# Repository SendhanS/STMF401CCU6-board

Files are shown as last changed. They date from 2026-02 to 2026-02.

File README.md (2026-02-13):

# STMF401CCU6-board
STM32F4 series breakout board

The breakout board is based on the STM32F401CCU6 microcontroller in a QFN-48 package, chosen
for its high-performance ARM Cortex-M4 core and compact footprint, providing sufficient digital and
communication interfaces for typical embedded applications while fitting within the 50 × 50 mm
board area. Power regulation is handled by the TLV75801PDRV low-dropout linear regulator, selected
for its compact SOT-23-5 package and ability to convert a 5 V input from USB or header to a stable
3.3 V supply required by the STM32F401 and peripherals.
Peripheral pin mapping follows assignment specifications: five GPIO outputs, I2C1 on PB6/PB7, SPI1
on PA5/PA6/PA7, USART2 on PA2/PA3, and SWD interface on a 2×5 header including SWDIO, SWCLK,
SWO, NRST, 3.3 V, and GND. To minimize routing complexity, peripherals are mapped to ensure all
related pins are on the same side of the MCU, preventing excessive trace crossings and overlap. The
reset button is connected to NRST with a parallel 0.1 μF capacitor, and a user LED is connected to
PC13 via a 1.5 kΩ series resistor.
Power and layout considerations prioritize clean routing and manufacturability. The 3.3 V rail is
decoupled with four 100 nF capacitors near the MCU and a 10 μF bulk capacitor at the
TLV75801PDRV output. The 8 MHz crystal is placed close to the MCU with a restricted area around its
traces to prevent noise coupling. A solid GND pour covers both layers, connecting decoupling caps,
mounting holes, and headers. Trace widths are 0.4 mm for power and 0.15–0.2 mm for signals,
following standard PCB design practice.

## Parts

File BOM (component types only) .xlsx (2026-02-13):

Designator | Package | Value
J4 | 1×6 pin header | SPI
C1 | 0805 SMD | 10uf
C10, C2, C3, C6, C8 | 0603 SMD | 100nf
C11, C12 | 0603 SMD | 10uF
C4, C7 | 0402 SMD | 12p
C5 | 0603 SMD | 0.1uf
C9 | 0603 SMD | 4.7uf
D1 | 0603 SMD LED | BLUE
D2 | 0603 SMD LED | LED
J7 | 1×2 pin header | Conn_01x02_Pin
J4 | 1×4 pin header | I2C
H1, H2, H3, H4 | 4.3 mm mounting hole for M4 | MountingHole_Pad
J2 | USB-C 6P SMT | USB_C_Receptacle_PowerOnly_6P
J3 | 1×4 pin header | USART2
J6 | 1×5 pin header | Digital Output
R1, R3 | 0402 SMD resistor | 4.7k
R10, R2 | 0603 SMD resistor | 10k
R4 | 0603 SMD resistor | 1.5k
R5, R6, R9 | 0603 SMD resistor | 5.1k
R7 | 0603 SMD resistor | 1M
R8 | 0603 SMD resistor | 200k
RESET1 | SPST switch -SMT | ~
J1 | 2×5 pin header | SWD
U1 | QFN-48, 7×7 mm | STM32F401CCUx
U2 | WSON-6, 2×2 mm | TLV75801PDRV
Y1 | SMD 3225 4-pin crystal, 3.2×2.5 mm | 8MHz

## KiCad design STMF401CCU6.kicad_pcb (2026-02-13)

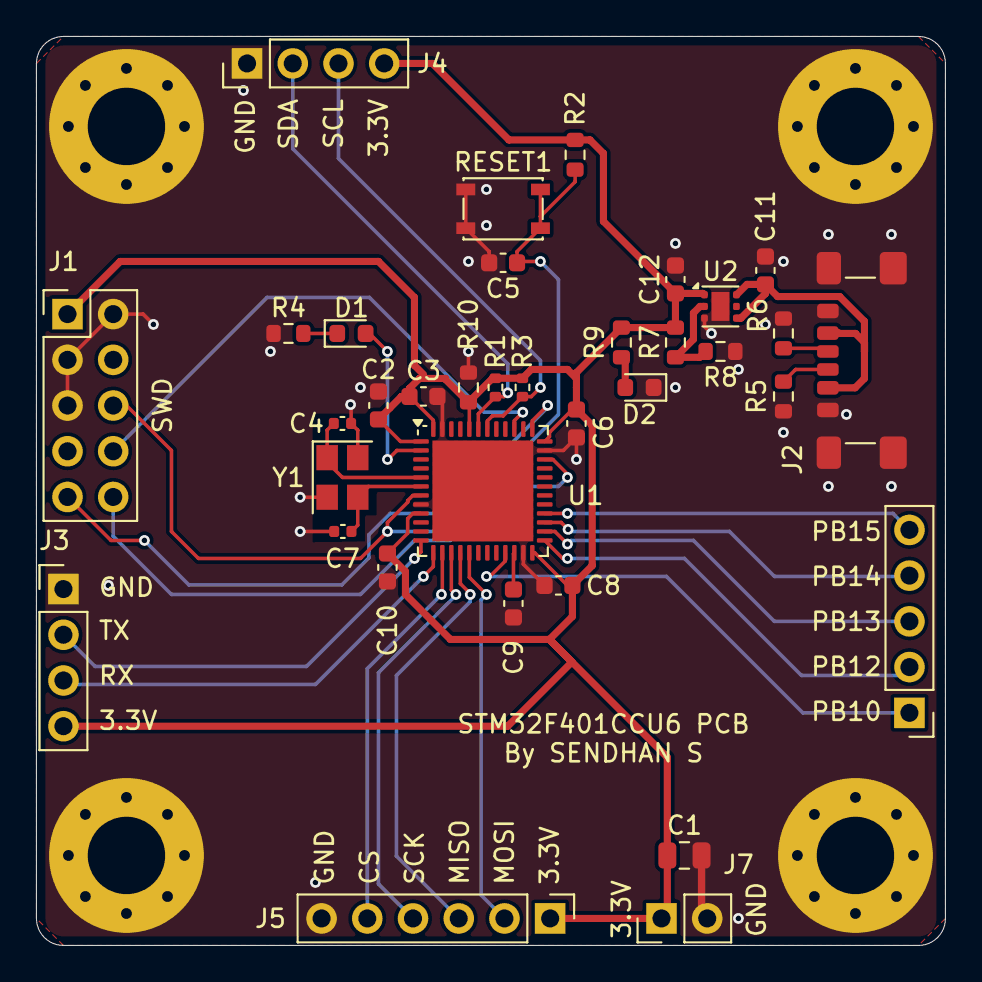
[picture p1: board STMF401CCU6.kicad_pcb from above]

Board: 2 copper layers, 50.5 x 50.5 mm, 39 parts (0 on the bottom side), 29 nets.

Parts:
3.3V: SPI; PinHeader_1x06_P2.54mm_Vertical
C1: 10uf; C_0805_2012Metric
C2, C3, C6, C8, C10: 100nf; C_0603_1608Metric
C4, C7: 12p; C_0402_1005Metric
C5: 0.1uf; C_0603_1608Metric
C9: 4.7uf; C_0603_1608Metric
C11, C12: 10uF; C_0603_1608Metric
D1: BLUE; LED_0603_1608Metric
D2: LED; LED_0603_1608Metric
GND: Conn_01x02_Pin; PinHeader_1x02_P2.54mm_Vertical
GND#2: I2C; PinHeader_1x04_P2.54mm_Vertical
H1, H2, H3, H4: MountingHole_Pad; MountingHole_4.3mm_M4_Pad_Via
J2: USB_C_Receptacle_PowerOnly_6P; USB_C_Receptacle_GCT_USB4135-GF-A_6P_TopMnt_Horizontal
J3: USART2; PinHeader_1x04_P2.54mm_Vertical
PB10: Digital Output; PinHeader_1x05_P2.54mm_Vertical
R1, R3: 4.7k; R_0402_1005Metric
R2, R10: 10k; R_0603_1608Metric
R4: 1.5k; R_0603_1608Metric
R5, R6, R9: 5.1k; R_0603_1608Metric
R7: 1M; R_0603_1608Metric
R8: 200k; R_0603_1608Metric
RESET1: SW_SPST_PTS810
SWD: SWD; PinHeader_2x05_P2.54mm_Vertical
U1: STM32F401CCUx; QFN-48-1EP_7x7mm_P0.5mm_EP5.6x5.6mm
U2: TLV75801PDRV; WSON-6-1EP_2x2mm_P0.65mm_EP1x1.6mm
Y1: 8MHz; Crystal_SMD_3225-4Pin_3.2x2.5mm

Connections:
/3V3: 3.3V.1, C1.1, C2.1, C3.1, C6.1, C8.1, C10.1, C12.1, GND.1, GND#2.4, J3.4, R1.1, R2.2, R3.1, R7.2, R9.1, R10.1, SWD.1, U1.1 (VBAT), U1.9 (VREF+), U1.24 (VDD), U1.36 (VDD), U1.44 (BOOT0), U1.48 (VDD), U2.1 (OUT)
/5VUSB: C11.1, J2.A9 (VBUS), J2.B9 (VBUS), U2.4 (EN), U2.6 (IN)
/CS: 3.3V.5, U1.14 (PA4)
/MISO: 3.3V.3, U1.16 (PA6)
/MOSI: 3.3V.2, U1.17 (PA7)
/NRST: C5.2, R2.1, RESET1.3 (K), RESET1.4 (A), SWD.6, U1.7 (NRST)
/PB10: PB10.1, U1.21 (PB10)
/PB12: PB10.2, U1.25 (PB12)
/PB13: PB10.3, U1.26 (PB13)
/PB14: PB10.4, U1.27 (PB14)
/PB15: PB10.5, U1.28 (PB15)
/RX: J3.3, U1.13 (PA3)
/SCK: 3.3V.4, U1.15 (PA5)
/SCL: GND#2.3, R3.2, U1.42 (PB6)
/SDA: GND#2.2, R1.2, U1.43 (PB7)
/SWCLK: SWD.9, U1.37 (PA14)
/SWDIO: SWD.10, U1.34 (PA13)
/SWO: SWD.8, U1.39 (PB3)
/TX: J3.2, U1.12 (PA2)
/USER_LED: D1.2 (A), U1.2 (PC13)
GND: 3.3V.6, C1.2, C2.2, C3.2, C4.2, C5.1, C6.2, C7.2, C8.2, C9.2, C10.2, C11.2, C12.2, D2.1 (K), GND.2, GND#2.1, H1.1, H2.1, H3.1, H4.1, J2.A12 (GND), J2.B12 (GND), J2.S1 (SHIELD), J3.1, R4.1, R5.2, R6.2, R8.1, R10.2, RESET1.1, RESET1.2, SWD.2, SWD.3, SWD.5, U1.8 (VSSA), U1.23 (VSS), U1.35 (VSS), U1.47 (VSS), U1.49 (VSS), U2.3 (GND), U2.7 (GND), Y1.2, Y1.4
unnamed: D1.1 (K), R4.2
unnamed: D2.2 (A), R9.2
unnamed: J2.A5 (CC1), R5.1
unnamed: J2.B5 (CC2), R6.1
unnamed: C4.1, U1.5 (PH0), Y1.1
unnamed: C7.1, U1.6 (PH1), Y1.3
unnamed: C9.1, U1.22 (VCAP1)
unnamed: R7.1, R8.2, U2.2 (FB)
